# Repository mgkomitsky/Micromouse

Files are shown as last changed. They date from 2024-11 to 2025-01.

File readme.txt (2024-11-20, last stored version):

Wichtige Hinweise zu den Nutzungsrechten
____________________________________

Die FAULHABER CAD 3D-Modelle sind eine kostenlose Service-Leistung der
Firma DR. FRITZ  FAULHABER GMBH & CO. KG, 71101 Schönaich (Germany).
Sie dürfen nur vollständig und unverändert genutzt oder weitergegeben werden.
Jegliche Veränderungen sind unzulässig und verstoßen gegen das Urheberrecht.

Alle Abmessungen sind in Millimeter angegeben. Dies muss insbesondere beim Laden
in CAD Systeme berücksichtigt werden, die auf anderen Einheiten basiert sind.
Es muss sichergestellt sein, dass die Abmessungen richtig übernommen werden!
Vor dem Import in die CAD Anwendung Millimeter einstellen!

Diese Zeichnungen sind nur als Hilfsmittel zu verstehen. Sie sind jedoch - insbesondere
in Hinblick auf die Abmessungen und den Lieferumfang - nicht verbindlich und
unterliegen keinem automatischen Änderungsdienst.
Aktuelle Zeichnungen können über das Internet heruntergeladen werden unter:

http://www.faulhaber.com

Wir bemühen uns um ständige Pflege und Verbesserung der Zeichnungen. Dennoch
können wir nicht garantieren, dass sie frei von Fehlern sind.
Die Nutzung der Daten erfolgt daher auf eigene Gefahr.

Durch die Benutzung der Daten erklären Sie sich mit diesen Bestimmungen einverstanden.

(c) Copyright 2013, DR.FRITZ FAULHABER GMBH & CO.KG.
Alle Rechte vorbehalten.

Conditions of Use
____________________________________

The FAULHABER CAD 3D-Drawings are a free service of
DR. FRITZ  FAULHABER GMBH & CO. KG, 71101 Schönaich (Germany).
They may only be used and distributed in a complete and unaltered form.
All copy rights reserved.

Please Note: All dimensions are displayed using the metric system (millimeters). 
Your CAD system maybe preset to another system of measurements or dimenstions.
Preset millimeter in the CAD application before importing the file!

These models are intended as a conceptual aid only. All dimensions are subject 
to change without notice. The most up-to-date drawings can be downloaded 
from the Internet at:

http://www.faulhaber.com

Though we encdeavor to maintain the accuracy of the models provided we can provide 
no guarantee of their accuracy.  Use of the models is at your own risk.

With the use of the data you agree with the aforementioned conditions.

(c) Copyright 2013, DR.FRITZ FAULHABER GMBH & CO.KG.
All rights reserved.

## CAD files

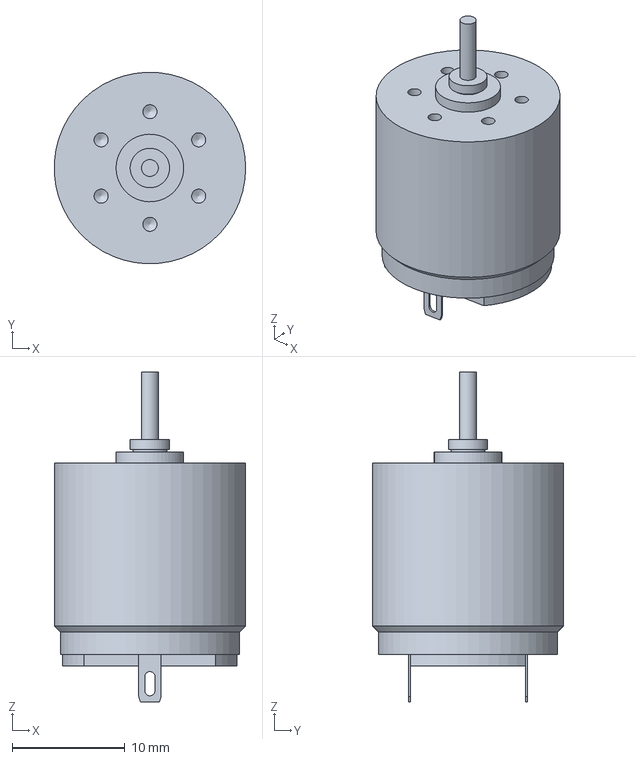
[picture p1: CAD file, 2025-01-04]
Micromouse/CAD/1717T_SR/1717T_SR.stp
17.0 x 17.0 x 29.3 mm

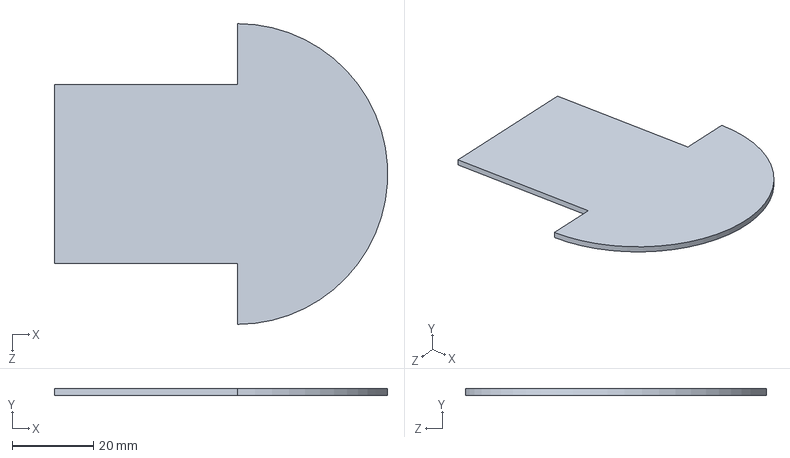
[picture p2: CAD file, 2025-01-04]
Micromouse/CAD/Chassis.SLDPRT
81.9 x 1.60 x 74.0 mm

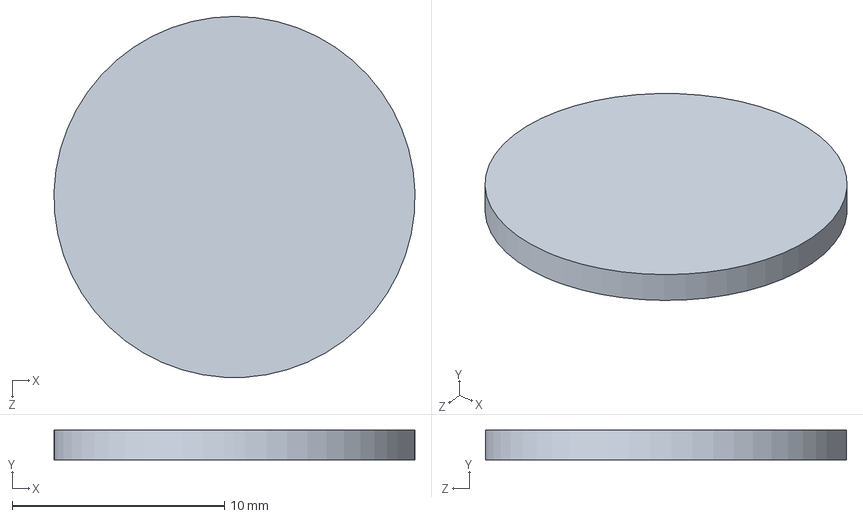
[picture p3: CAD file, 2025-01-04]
Micromouse/CAD/encoder.SLDPRT
17.0 x 1.40 x 17.0 mm

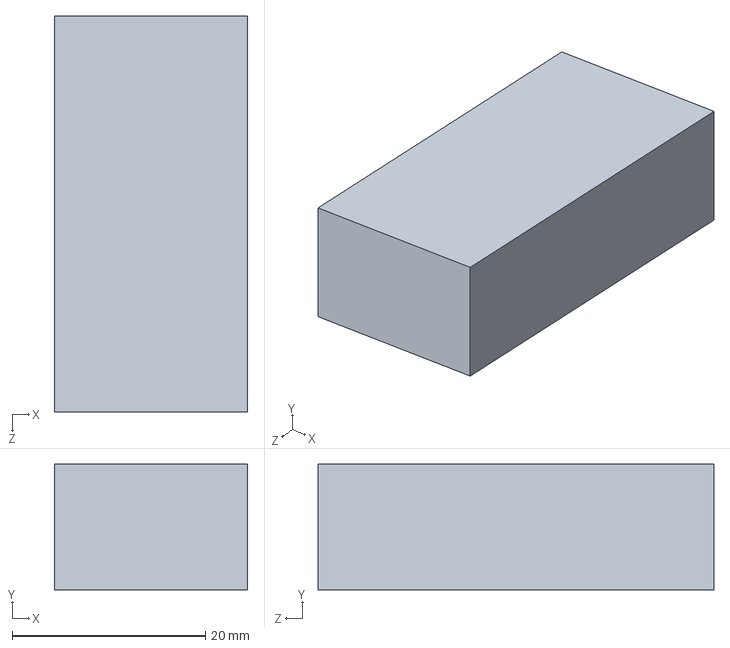
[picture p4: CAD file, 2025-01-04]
Micromouse/CAD/Battery.SLDPRT
20.0 x 13.0 x 41.0 mm

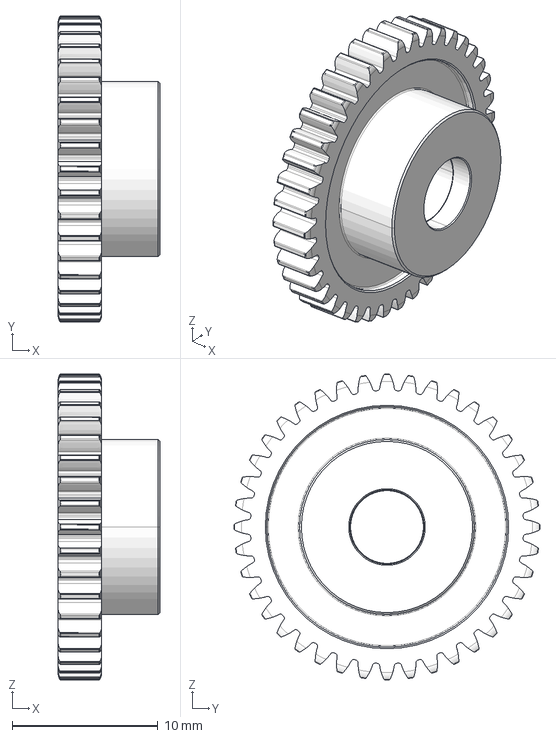
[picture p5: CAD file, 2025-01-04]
Micromouse/CAD/KHK-US_DS0_5-40.stp
7.00 x 21.0 x 21.0 mm

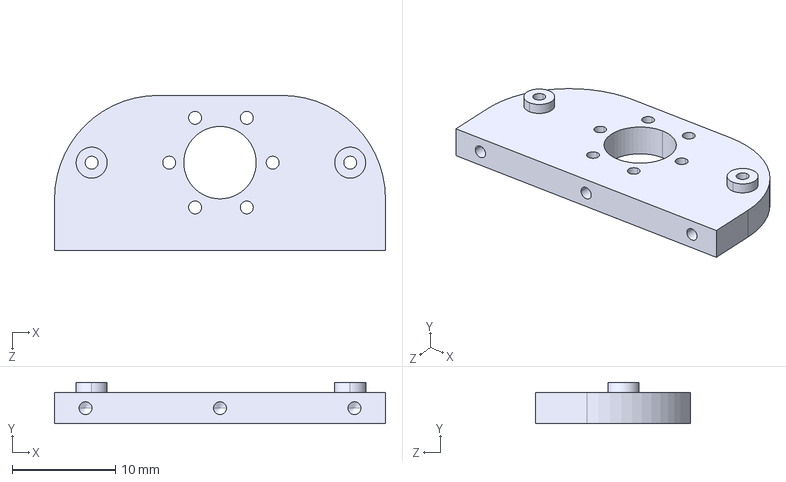
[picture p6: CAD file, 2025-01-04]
Micromouse/CAD/motorMount2.STEP
32.0 x 4.00 x 15.0 mm

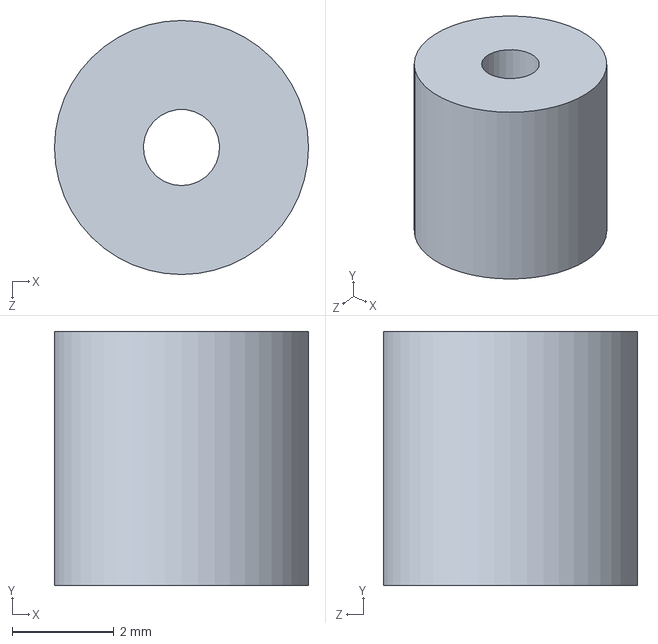
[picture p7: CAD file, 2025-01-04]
Micromouse/CAD/pinion.SLDPRT
5.00 x 5.00 x 5.00 mm

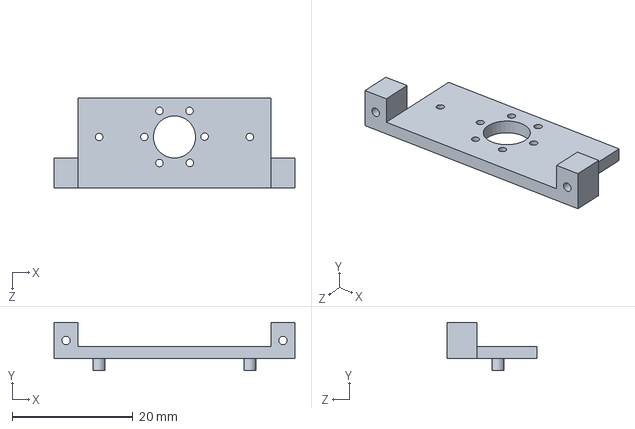
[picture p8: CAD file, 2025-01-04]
Micromouse/CAD/Motor Mount.SLDPRT
40.0 x 8.00 x 15.0 mm

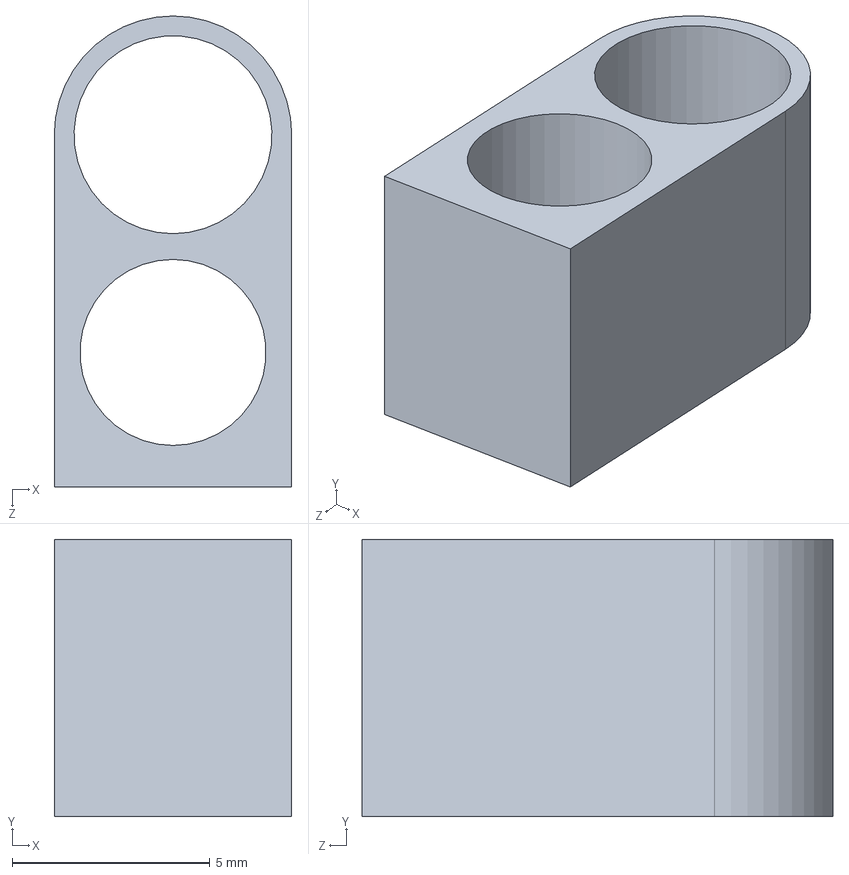
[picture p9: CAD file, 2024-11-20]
Micromouse/CAD/Sensor Mounts.SLDPRT
6.00 x 7.00 x 11.9 mm

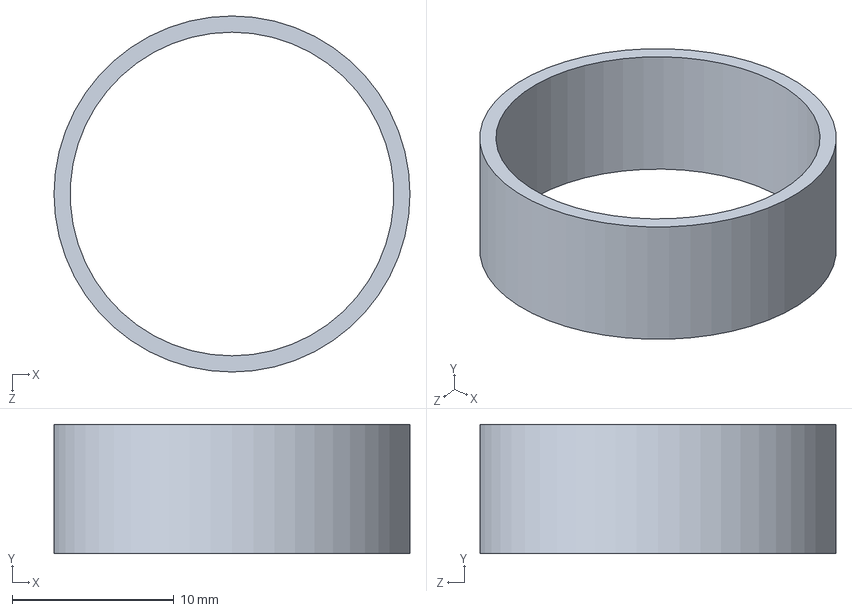
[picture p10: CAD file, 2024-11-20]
Micromouse/CAD/Tire.SLDPRT
22.0 x 8.00 x 22.0 mm

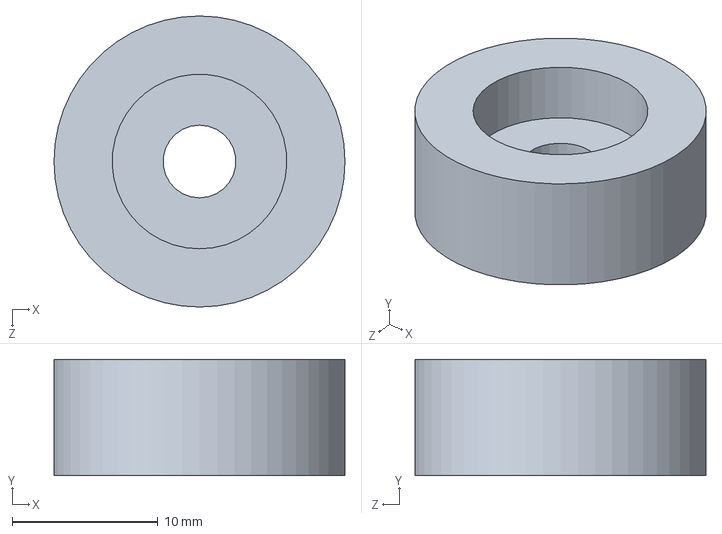
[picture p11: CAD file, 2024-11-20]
Micromouse/CAD/Wheel_2.SLDPRT
20.0 x 8.00 x 20.0 mm

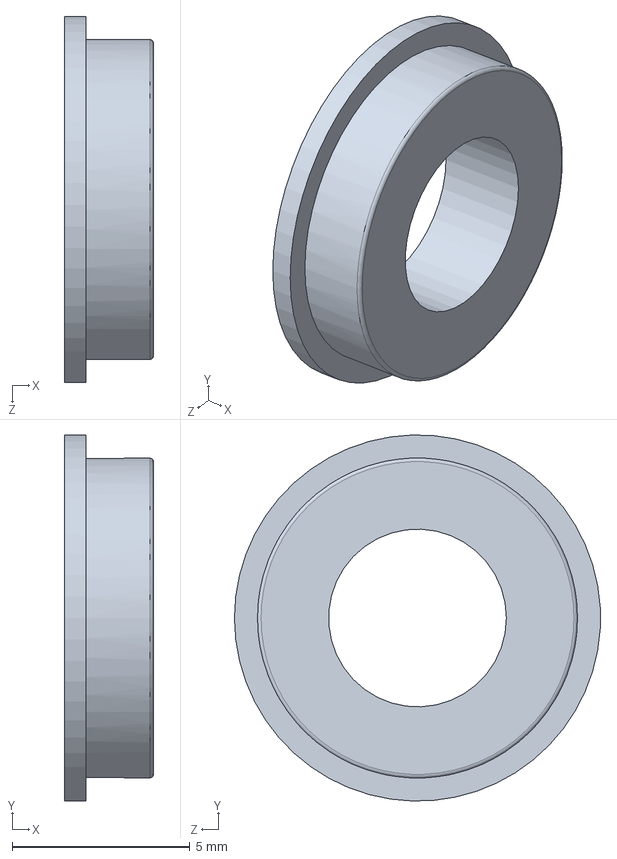
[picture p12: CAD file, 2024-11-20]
Micromouse/CAD/Bearing_SF684.SLDPRT
2.50 x 10.3 x 10.3 mm

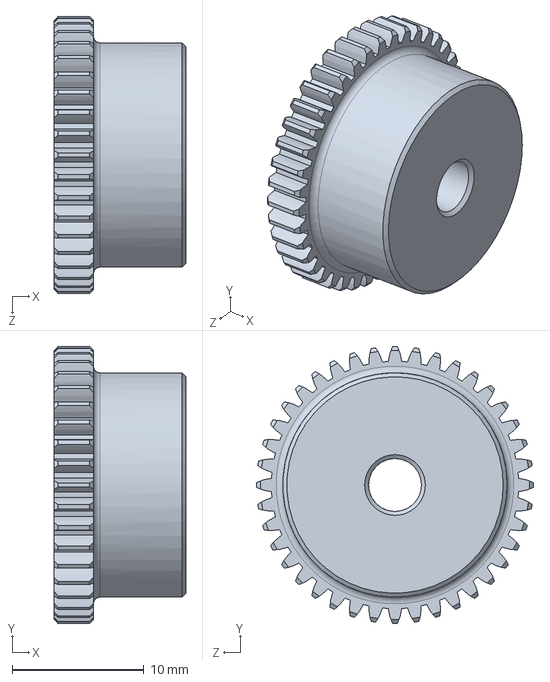
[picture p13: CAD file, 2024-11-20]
Micromouse/CAD/BSS0.5-40_On.SLDPRT
10.0 x 21.0 x 21.0 mm

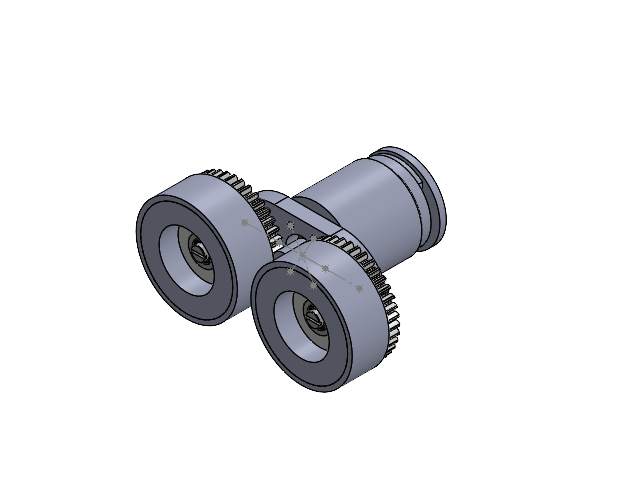
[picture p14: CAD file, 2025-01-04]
Micromouse/CAD/Assem4.SLDASM
1717T_SR
KHK-US_DS0_5-40 x 2
57155K528_Stainless Steel Ball Bearing x 4
90270A221_Slotted 18-8 Stainless Steel Precision Shoulder Screw x 2
Tire x 2
Wheel_2 x 2
pinion
encoder
motorMount2

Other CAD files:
Micromouse/CAD/Assem2.SLDASM
Micromouse/CAD/Assem5.SLDASM
Micromouse/CAD/Assem3.SLDASM
Micromouse/CAD/Micromouse.SLDASM
Micromouse/CAD/1717T_SR.SLDPRT
Micromouse/CAD/1717T_SR/1717T_SR.igs
Micromouse/CAD/1717T_SR/1717T_SR.x_t
Micromouse/CAD/57155K643_Flanged Ball Bearing.SLDPRT
Micromouse/CAD/7804K135_Stainless Steel Ball Bearing.SLDPRT
Micromouse/CAD/91290A020_Alloy Steel Socket Head Screw.SLDPRT
Micromouse/CAD/91800A011_18-8 Stainless Steel Narrow Cheese Head Slotted Screws.SLDPRT
Micromouse/CAD/92010A815_Passivated 18-8 Stainless Steel Phillips Flat Head Screw.SLDPRT
Micromouse/CAD/Fan.SLDPRT
Micromouse/CAD/KHK-US_DS0_5-40.SLDPRT
Micromouse/CAD/Wheel.SLDPRT
Micromouse/CAD/Wheel_2.STL
Micromouse/CAD/motorMount2.SLDDRW
Micromouse/CAD/motorMount2.SLDPRT

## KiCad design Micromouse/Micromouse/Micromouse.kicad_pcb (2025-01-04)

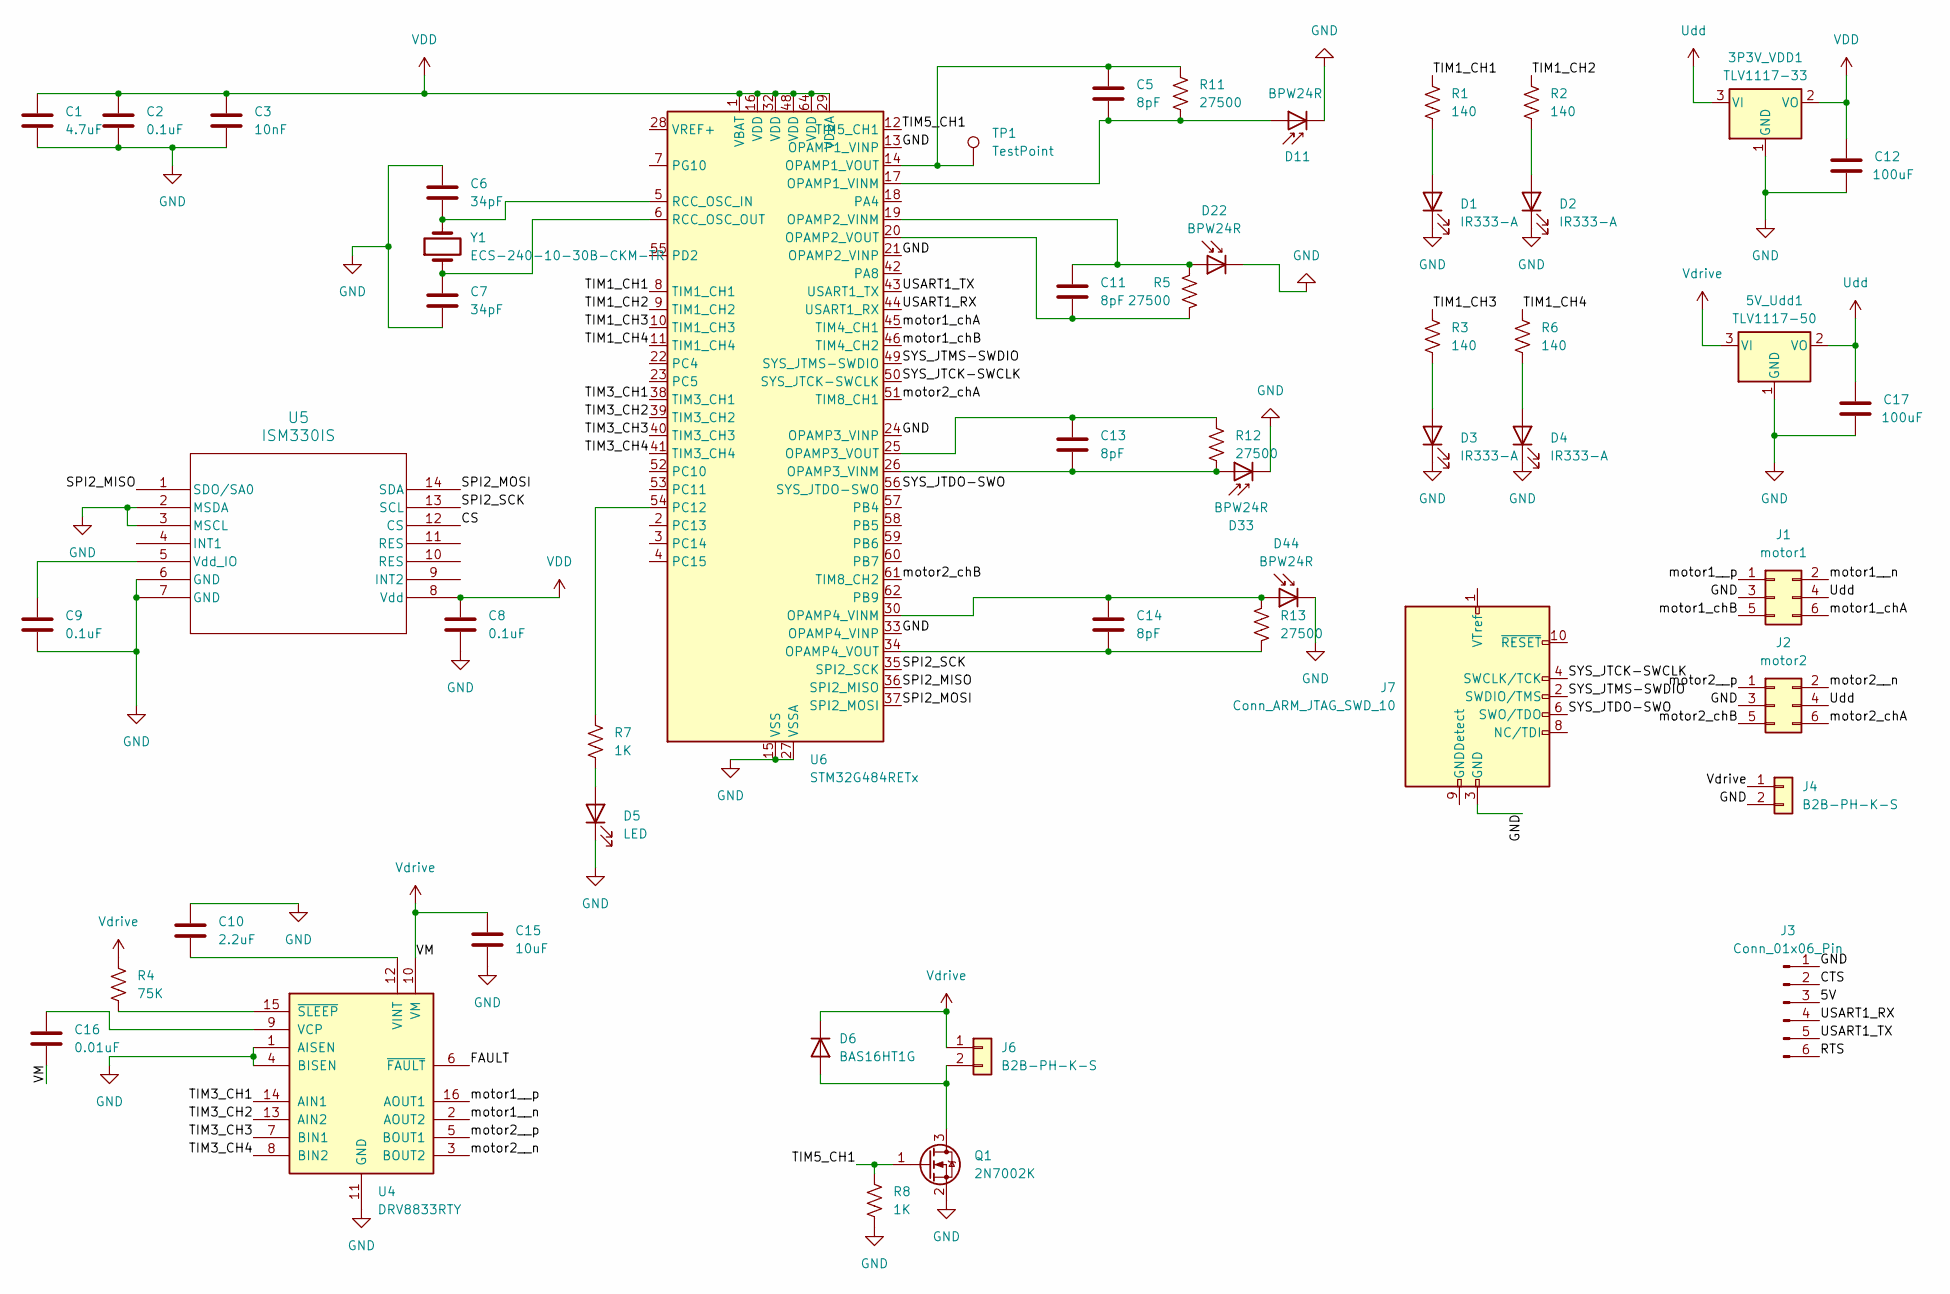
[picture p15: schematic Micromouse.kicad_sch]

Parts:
3P3V_VDD1: TLV1117-33; WSON-8-1EP_4x4mm_P0.8mm_EP2.2x3mm_ThermalVias
5V_Udd1: TLV1117-50; WSON-8-1EP_4x4mm_P0.8mm_EP2.2x3mm_ThermalVias
C1: 4.7uF; C_0805_2012Metric
C2, C8, C9: 0.1uF; C_0805_2012Metric
C3: 10nF; C_0805_2012Metric
C5, C11, C13, C14: 8pF; C_0805_2012Metric
C6, C7: 34pF; C_0805_2012Metric
C10: 2.2uF; C_0805_2012Metric
C12, C17: 100uF; C_0805_2012Metric
C15: 10uF; C_0805_2012Metric
C16: 0.01uF; C_0805_2012Metric
D1, D2, D3, D4: IR333-A; LED_D5.0mm
D5: LED; LED_0805_2012Metric
D6: BAS16HT1G; D_SOD-323
D11, D22, D33, D44: BPW24R; TO-18-2
J1: motor1; IDC-Header_2x03_P2.54mm_Vertical
J2: motor2; IDC-Header_2x03_P2.54mm_Vertical
J3: Conn_01x06_Pin; PinHeader_1x06_P2.54mm_Vertical
J4, J6: B2B-PH-K-S; JST_PH_B2B-PH-K_1x02_P2.00mm_Vertical
J7: Conn_ARM_JTAG_SWD_10; PinHeader_2x05_P1.27mm_Vertical_SMD
Q1: 2N7002K; SOT-23
R1, R2, R3, R6: 140; R_0805_2012Metric
R4: 75K; R_0805_2012Metric
R5, R11, R12, R13: 27500; R_0805_2012Metric
R7, R8: 1K; R_0805_2012Metric
TP1: TestPoint; PinHeader_1x01_P2.54mm_Vertical
U4: DRV8833RTY; Texas_RTY_WQFN-16-1EP_4x4mm_P0.65mm_EP2.1x2.1mm_ThermalVias
U5: ISM330IS; LGA-14L_2P5X3X0P83_STM
U6: STM32G484RETx; LQFP-64_10x10mm_P0.5mm
Y1: ECS-240-10-30B-CKM-TR; ECX-53BSMD CRYSTAL

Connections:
/5V: J3.3
/CS: U5.12 (CS)
/CTS: J3.2
/FAULT: U4.6 (~FAULT)
/RTS: J3.6
/SPI2_MISO: U5.1 (SDO/SA0), U6.36 (SPI2_MISO)
/SPI2_MOSI: U5.14 (SDA), U6.37 (SPI2_MOSI)
/SPI2_SCK: U5.13 (SCL), U6.35 (SPI2_SCK)
/SYS_JTCK-SWCLK: J7.4 (SWCLK/TCK), U6.50 (SYS_JTCK-SWCLK)
/SYS_JTDO-SWO: J7.6 (SWO/TDO), U6.56 (SYS_JTDO-SWO)
/SYS_JTMS-SWDIO: J7.2 (SWDIO/TMS), U6.49 (SYS_JTMS-SWDIO)
/TIM1_CH1: R1.1, U6.8 (TIM1_CH1)
/TIM1_CH2: R2.1, U6.9 (TIM1_CH2)
/TIM1_CH3: R3.1, U6.10 (TIM1_CH3)
/TIM1_CH4: R6.1, U6.11 (TIM1_CH4)
/TIM3_CH1: U4.14 (AIN1), U6.38 (TIM3_CH1)
/TIM3_CH2: U4.13 (AIN2), U6.39 (TIM3_CH2)
/TIM3_CH3: U4.7 (BIN1), U6.40 (TIM3_CH3)
/TIM3_CH4: U4.8 (BIN2), U6.41 (TIM3_CH4)
/TIM5_CH1: Q1.1 (G), R8.1, U6.12 (TIM5_CH1)
/USART1_RX: J3.4, U6.44 (USART1_RX)
/USART1_TX: J3.5, U6.43 (USART1_TX)
/motor1__n: J1.2, U4.2 (AOUT2)
/motor1__p: J1.1, U4.16 (AOUT1)
/motor1_chA: J1.6, U6.45 (TIM4_CH1)
/motor1_chB: J1.5, U6.46 (TIM4_CH2)
/motor2__n: J2.2, U4.3 (BOUT2)
/motor2__p: J2.1, U4.5 (BOUT1)
/motor2_chA: J2.6, U6.51 (TIM8_CH1)
/motor2_chB: J2.5, U6.61 (TIM8_CH2)
GND: 3P3V_VDD1.1 (GND), 5V_Udd1.1 (GND), C1.1, C2.1, C3.1, C6.2, C7.1, C8.1, C9.1, C10.2, C12.1, C15.1, C17.1, D1.1 (K), D2.1 (K), D3.1 (K), D4.1 (K), D5.1 (K), D11.1 (K), D22.1 (K), D33.1 (K), D44.1 (K), J1.3, J2.3, J3.1, J4.2, J7.3 (GND), J7.5 (GND), Q1.2 (S), R8.2, U4.1 (AISEN), U4.4 (BISEN), U4.11 (GND), U4.17 (GND), U5.2 (MSDA), U5.3 (MSCL), U5.6 (GND), U5.7 (GND), U6.13 (OPAMP1_VINP), U6.15 (VSS), U6.21 (OPAMP2_VINP), U6.24 (OPAMP3_VINP), U6.27 (VSSA), U6.31 (VSS), U6.33 (OPAMP4_VINP), U6.47 (VSS), U6.63 (VSS)
unnamed: D1.2 (A), R1.2
unnamed: D2.2 (A), R2.2
unnamed: D3.2 (A), R3.2
unnamed: D4.2 (A), R6.2
unnamed: D5.2 (A), R7.2
unnamed: D6.2 (A), J6.2, Q1.3 (D)
unnamed: C5.1, D11.2 (A), R11.1, U6.17 (OPAMP1_VINM)
unnamed: C11.1, D22.2 (A), R5.1, U6.19 (OPAMP2_VINM)
unnamed: C13.1, D33.2 (A), R12.1, U6.26 (OPAMP3_VINM)
unnamed: C14.1, D44.2 (A), R13.1, U6.30 (OPAMP4_VINM)
unnamed: C16.2, U4.9 (VCP)
unnamed: C10.1, U4.12 (VINT)
unnamed: R4.2, U4.15 (~SLEEP)
unnamed: C9.2, U5.5 (Vdd_IO)
unnamed: C5.2, R11.2, TP1.1, U6.14 (OPAMP1_VOUT)
unnamed: C11.2, R5.2, U6.20 (OPAMP2_VOUT)
unnamed: C13.2, R12.2, U6.25 (OPAMP3_VOUT)
unnamed: C14.2, R13.2, U6.34 (OPAMP4_VOUT)
unnamed: R7.1, U6.54 (PC12)
unnamed: C6.1, U6.5 (RCC_OSC_IN), Y1.2
unnamed: C7.2, U6.6 (RCC_OSC_OUT), Y1.1
Udd: 3P3V_VDD1.3 (VI), 5V_Udd1.2 (VO), C17.2, J1.4, J2.4
VDD: 3P3V_VDD1.2 (VO), C1.2, C2.2, C3.2, C8.2, C12.2, U5.8 (Vdd), U6.1 (VBAT), U6.16 (VDD), U6.29 (VDDA), U6.32 (VDD), U6.48 (VDD), U6.64 (VDD)
Vdrive: 5V_Udd1.3 (VI), C15.2, C16.1, D6.1 (K), J4.1, J6.1, R4.1, U4.10 (VM)

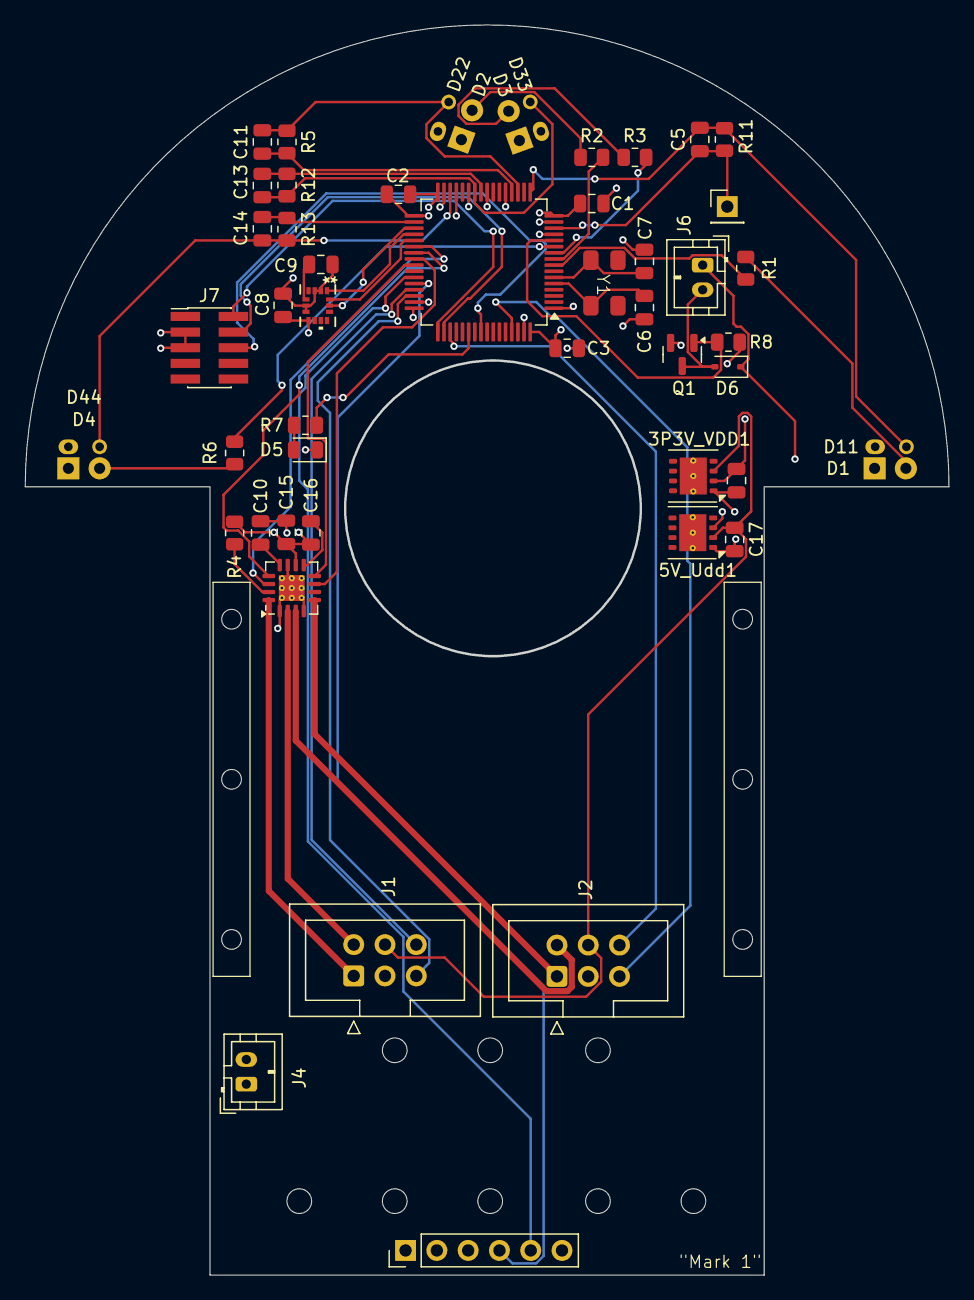
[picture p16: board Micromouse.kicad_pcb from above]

Board: 4 copper layers, 75.0 x 101.5 mm, 51 parts (0 on the bottom side), 50 nets.

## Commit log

2025-01-04 removed old files
    [1717T_SR.SLDPRT, 57155K643_Flanged Ball Bearing.SLDPRT, 7804K135_Stainless Steel Ball Bearing.SLDPRT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]
2025-01-04 updated files
    [1717T_SR.SLDPRT, 1717T_SR.igs, 1717T_SR.stp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]
2025-01-04 vdrive trace routing
    [Micromouse.kicad_pcb]
